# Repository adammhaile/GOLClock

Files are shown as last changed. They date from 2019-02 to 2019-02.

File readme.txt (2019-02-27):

Clock Faces and DIP switch settings:

000 - forwardClock - Shows the current time and date for 4 seconds, then plays "Conway's Game of Life" with the lit LEDs for the remainder of the minute.

001 - staticClock - Starts with completely random static, and then resolves to mostly clear numbers showing the date and time.  The "correctly" lit pixels still have a chance to turn off and vice versa, so it is never perfectly displayed. Requires some motion sensing ability to read the time.

010 - meltClock - Displays the current time and date, and then randomly makes lit pixels start falling to the bottom of the display. After about 15-20 seconds, becomes unreadable.

011 - brightClock - Each fully lit column is one hour in the day, starting from the left edge. Partially lit lines represent the portion of the current hour, with 3.75 minute resolution.

100 - backwardClock - Plays the Game of Life... but in reverse!  It iterates through the game about 30 steps, displays the output, then goes back to the start and iterates 29 times, shows the output, etc... until it's back to 0 steps, and then it just shows the correct time for a few seconds, until it starts the process over.  As the minute progresses, the display speeds up since it takes a non-trivial amount of time to iterate 30 times through the Game (roughly 3.1 seconds for 30 iterations, and .1 seconds for a single iteration.) 

101 - chartClock - Displays a bar graph that shows the approximate fraction of 5 different time durations, from top to bottom year, month, day, hour, and minute.  The minute hand has a 2.5 second resolution... Everything above that is way worse.

110 - binaryClock - Displays the current hours, minutes, and seconds, in binary format. Each row of boxes is one segment of the clock, and the filled boxes represent "on" bits of the time.

111 - epochClock - Displays the decimal notation of the current epoch time. *NOTE* it does not account for timezone differences. Not for use for mission critical timekeeping, because unless you live in GMT-0, it will be off.
ToDo: add in some sort of time zone functionality while setting the time. Of course, that would only be useful for this clock, so very low priority. 

Setting the clock: Hold both buttons until "Year 13" appears. Use the left hand button (when looking at the display) to advance the number, and the right hand button to change the set mode.  Hold down the right button to cancel out, and both buttons to save the new time and return to the clock function.  Note: In some clock faces, you may hold both buttons for more than a second, but the display won't change to the set mode until the start of the next minute.

Setting brightness: DIP switch #4 controls the brightness. Off is dim, on is bright.  The clock checks this setting at the top of each minute for most clocks, so it could take up to a minute for a change to take effect. (cycling power to the clock will force an update, of course)

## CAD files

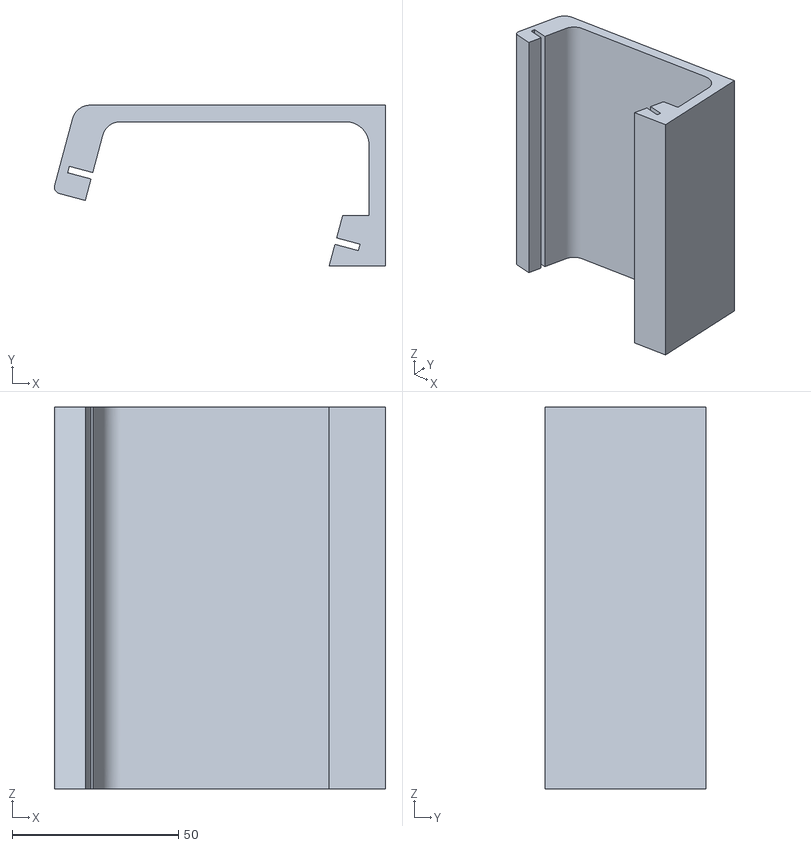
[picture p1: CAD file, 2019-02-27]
3D Models/STANDTHING_3D.stl
99.7 x 48.4 x 115.0

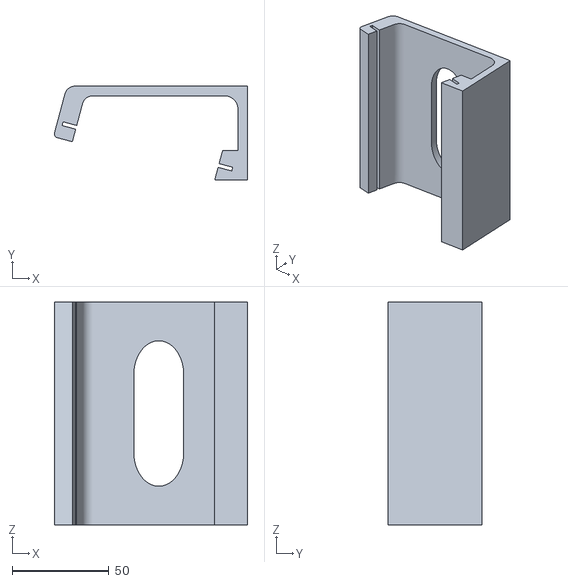
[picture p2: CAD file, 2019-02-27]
3D Models/STANDTHING_3D_Holy.stl
99.7 x 48.4 x 115.0

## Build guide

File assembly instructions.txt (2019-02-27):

Step 1: Solder together the pads on J5 on the back of the LED matrix. That tells the matrix that it's the first one in the chain.

Step 2: Solder the 10K resistor (Brown, Black, Orange) into R1

Step 3: Solder the 110 ohm resistor (Brown, Brown, Brown) into R2.

Step 4-whatever: Solder the rest of the components on the front of the board. Be sure the DIP switch panel is facing the right way up (the same orientation as the words "Josh Ward Game of Life Clock v1.0")

Step 5: Solder the 10-pin socket to P1, on the bottom of the board.

Step 6: Solder the 5-pin socket to the OUTSIDE pins of P2.  It will require a tiny bit of bending in order to place it in the socket.

Step 7: Plug the entire board into the back of the LED Matrix, ensuring that P1 is in the socket closest to J5.

Step 8: Plug it into a USB cable, and marvel at it actually working!  DIP settings below... Unplug and replug it to make sure new clock faces take effect immediately, and are cleanly drawn.

000 - forwardClock

001 - staticClock

010 - meltClock

011 - brightClock 

100 - backwardClock

101 - chartClock 

110 - binaryClock 

111 - epochClock 

Switch #4 is used for brightness settings.  Either very bright, or very dim.

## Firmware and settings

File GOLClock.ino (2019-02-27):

/*
* Conway's "Life" Clock works backwards, showing "random" display that reassembles to clock face... still in progress!
* It also does other modes, some of which are still being figured out and refined.
* Adapted from the Life example
* on the Processing.org site
*
* Further adapted by Josh Ward
* 
*/
#include <Wire.h>
#include "HT1632.h"
#include "RTClib.h"

RTC_DS1307 RTC;

#define DATA 12
#define WR   13
#define CS   4
#define DELAY 500

HT1632LEDMatrix matrix = HT1632LEDMatrix(DATA, WR, CS);

#include "globals.h"
#include "drawing.h"
#include "numbers.h"
#include "settime.h"
uint8_t BRIGHT = 1;

void setup() {
	timeRef = 0;

	//Set PORTD2 and PORTD3 as inputs
	DDRD &= ~(_BV(PIND2) | _BV(PIND3));
	//Enable set/change button pullups
	PORTD |= (_BV(PIND2) | _BV(PIND3));
	//Enable I2C pullups - probably not really necessary since twi.h does this for you
	PORTC |= (_BV(PINC4) | _BV(PINC5));

	//see setResetDisable(bool) for info
	DDRD &= ~(_BV(PIND5)); //Set PIND5 as input initially
	PORTD |= (_BV(PIND5)); //Set high

	//check for buttons held down at power up
	bSave = BUTTON_STATE;

	Serial.begin(115200);
	Wire.begin();
	RTC.begin();

	pinMode(17, OUTPUT); //These two are ONLY used while it's on the Arduino. When moved to actual device, delete these!
	pinMode(16, OUTPUT);

	pinMode(8, INPUT);
	pinMode(9, INPUT);
	pinMode(10, INPUT);
	pinMode(11, INPUT);
	digitalWrite(2, HIGH);
	digitalWrite(3, HIGH);
	digitalWrite(8, HIGH);
	digitalWrite(9, HIGH);
	digitalWrite(10, HIGH);
	digitalWrite(11, HIGH);

	digitalWrite(17, HIGH); //These two are ONLY used while it's on the Arduino. When moved to actual device, delete these!
	digitalWrite(16, LOW);

	if (digitalRead(11) == LOW)
		BRIGHT = 1;
	else if (digitalRead(11) == HIGH)
		BRIGHT = 5;

	matrix.begin(HT1632_COMMON_16NMOS); 
	matrix.setBrightness(BRIGHT);
	matrix.fillScreen();
	delay(500);
	matrix.clearScreen();

	uint8_t hour = 0;
	uint8_t hourten = 0;
	uint8_t hourone = 0;
	uint8_t minute = 0;
	uint8_t minuteten = 0;
	uint8_t minuteone = 0;
	uint8_t top = 0;
	uint8_t egg = 0;

	//Grab current time and set to compile time if RTC is uniitialized

	dt_now = RTC.now();

	if(dt_now.unixtime() <= 946684860) //RTC not initialized and oscillator disabled
	{
		dt_now = DateTime(__DATE__, __TIME__);
		RTC.adjust(dt_now);
	}

	setInterrupts();
	setupDisplayTimer();
}

void loop() {
	if(curState == STATE_CLOCK)
	{  
		static DateTime now;
		now = RTC.now();
		dt_now = RTC.now();
		if (digitalRead(11) == HIGH)
			BRIGHT = 1;
		else if (digitalRead(11) == LOW)
			BRIGHT = 15;
		matrix.setBrightness(BRIGHT);
		if ((digitalRead(8) == HIGH) && (digitalRead(9) == HIGH) && (digitalRead(10) == HIGH)) //000
			forwardClock(now);
		else if ((digitalRead(8) == HIGH) && (digitalRead(9) == HIGH) && (digitalRead(10) == LOW)) //001
			staticClock(now);
		else if ((digitalRead(8) == HIGH) && (digitalRead(9) == LOW) && (digitalRead(10) == HIGH)) //010
			meltClock(now);
		else if ((digitalRead(8) == HIGH) && (digitalRead(9) == LOW) && (digitalRead(10) == LOW)) //011
			brightClock(now);
		else if ((digitalRead(8) == LOW) && (digitalRead(9) == HIGH) && (digitalRead(10) == HIGH)) //100
			backwardClock(now);
		else if ((digitalRead(8) == LOW) && (digitalRead(9) == HIGH) && (digitalRead(10) == LOW)) //101
			chartClock(now);
		else if ((digitalRead(8) == LOW) && (digitalRead(9) == LOW) && (digitalRead(10) == HIGH)) //110
			binaryClock(now);
		else if ((digitalRead(8) == LOW) && (digitalRead(9) == LOW) && (digitalRead(10) == LOW)) //111
			epochClock(now);
	}
	else if(curState == STATE_MANUAL_SET)
	{
		matrix.setTextSize(1);    // size 1 == 8 pixels high
		matrix.setTextColor(1);   // 'lit' LEDs
		if(timeReady)
		{
			adjustFromSetVal();
			curState = STATE_CLOCK; 
		}
		else if(setChanged)
		{

			//This is where all the time setting code goes!
			switch(curSet) {
			case SET_YR:
				matrix.clearScreen(); 
				matrix.setCursor(0, 0);   // start at top left, with one pixel of spacing
				matrix.print("Year ");
				matrix.setCursor(0, 8);   // next line, 8 pixels down
				matrix.print(setValues[SET_YR]);
				matrix.writeScreen();
				break;
			case SET_MON:
				matrix.clearScreen(); 
				matrix.setCursor(0, 0);   // start at top left, with one pixel of spacing
				matrix.print("Mon ");
				matrix.setCursor(0, 8);   // next line, 8 pixels down
				matrix.print(setValues[SET_MON]);
				matrix.writeScreen();
				break;
			case SET_DAY:
				matrix.clearScreen(); 
				matrix.setCursor(0, 0);   // start at top left, with one pixel of spacing
				matrix.print("Day ");
				matrix.setCursor(0, 8);   // next line, 8 pixels down
				matrix.print(setValues[SET_DAY]);
				matrix.writeScreen();
				break;
			case SET_HR:
				matrix.clearScreen(); 
				matrix.setCursor(0, 0);   // start at top left, with one pixel of spacing
				matrix.print("Hour ");
				matrix.setCursor(0, 8);   // next line, 8 pixels down
				matrix.print(setValues[SET_HR]);
				matrix.writeScreen();  
				break;
			case SET_MIN:
				matrix.clearScreen(); 
				matrix.setCursor(0, 0);   // start at top left, with one pixel of spacing
				matrix.print("Min ");
				matrix.setCursor(0, 8);   // next line, 8 pixels down
				matrix.print(setValues[SET_MIN]);
				matrix.writeScreen(); 
				break; 
			}
			setChanged = false;
		}
		else if(setCancel)
		{
			curState = STATE_CLOCK;
		}

	}
}

void backwardClock(DateTime now) {
	DateTime future = now.unixtime() + 60; //it's gonna be the future soon
	displayTime(future);
	for (int bigsteps = 29; bigsteps > -1; bigsteps--) {
		// 32 steps is the most I can fit in a minute right now.  
		//save the time back into world 0
		for (uint8_t y = 0; y < matrix.height(); y++) { 
			for (uint8_t x = 0; x < matrix.width(); x++) {
				setDispPixel(x, y, 0, getDispPixel(x, y, 2));
			}
		}
		cycle(bigsteps); // Play the game of life "bigsteps" number of times 
	} //end for loop

} //end backwardClock



void forwardClock(DateTime now) {
	displayTime(now);
	for (uint8_t y = 0; y < matrix.height(); y++) { 
		for (uint8_t x = 0; x < matrix.width(); x++) {
			setDispPixel(x, y, 0, getDispPixel(x, y, 2));
		}
	}

	displayFrame();
	delay(4000);
	for (uint8_t y = 0; y < matrix.height(); y++) { 
		for (uint8_t x = 0; x < matrix.width(); x++) {
			setDispPixel(x, y, 0, getDispPixel(x, y, 2));
		}
	}
	while(1) { 
		//save the time back into world 0

		for (uint8_t y = 0; y < matrix.height(); y++) { 
			for (uint8_t x = 0; x < matrix.width(); x++) {
				// Default is for cell to stay the same
				setDispPixel(x, y, 1, getDispPixel(x, y, 0));
				uint8_t count = neighbours(x, y); 

				if (count == 3 && !(getDispPixel(x, y, 0))) {
					// A new cell is born
					setDispPixel(x, y, 1, 1);
				} 

				if ((count < 2 || count > 3) && getDispPixel(x, y, 0)) {
					// Cell dies
					setDispPixel(x, y, 1, 0);
				}
			}
		}
		// Copy next generation into place
		for (uint8_t y = 0; y < matrix.height(); y++) { 
			for (uint8_t x = 0; x < matrix.width(); x++) {
				setDispPixel(x, y, 0, getDispPixel(x, y, 1));
			} 
		}
		displayFrame();
		DateTime now = RTC.now();
		if (now.second() >= 58)
			break;

	} //end GOL loop
} //end forwardClock

void staticClock(DateTime now) { //Cull the current time out of static...
	displayTime(now);

	randomSeed(analogRead(5));
	for (uint8_t y = 0; y < matrix.height(); y++) { 
		for (uint8_t x = 0; x < matrix.width(); x++) {
			randPixel(x, y, 0, 90);
		}
	}
	displayFrame();
	while (1) {  
		for (uint8_t y = 0; y < matrix.height(); y++) { 
			for (uint8_t x = 0; x < matrix.width(); x++) {
				if ((getDispPixel(x, y, 0) == getDispPixel(x, y, 2)) && !(getDispPixel(x, y, 0))) {
					if (random(100) < 80) //Change 80 for different densities of correct pixels
						setDispPixel(x, y, 1, getDispPixel(x, y, 0));
					else
						randPixel(x, y, 1, 50);
				} 
				else if ((getDispPixel(x, y, 0) == getDispPixel(x, y, 2)) && (getDispPixel(x, y, 0))) {
					if (random(100) < 98) //Change 98 for different densities of correct pixels
						setDispPixel(x, y, 1, getDispPixel(x, y, 0));
					else
						randPixel(x, y, 1, 50);
				}
				else {
					randPixel(x, y, 1, 50);
				}
			}
		}
		//copy new frame into current  
		for (uint8_t y = 0; y < matrix.height(); y++) { 
			for (uint8_t x = 0; x < matrix.width(); x++) {
				setDispPixel(x, y, 0, getDispPixel(x, y, 1));
			} 
		}
		displayFrame();
		DateTime now = RTC.now();
		if (now.second() >= 58)
			break;
	}
} // end staticClock


void meltClock(DateTime now) { //melt the time...
	displayTime(now);
	for (uint8_t y = 0; y < matrix.height(); y++) { //show the current time
		for (uint8_t x = 0; x < matrix.width(); x++) {
			setDispPixel(x, y, 0, getDispPixel(x, y, 2));
		} 
	}
	displayFrame();
	delay(4000);
	randomSeed(analogRead(5));

	while (1) {  
		for (uint8_t y = 0; y < matrix.height(); y++) { 
			for (uint8_t x = 0; x < matrix.width(); x++) {
				meltPixel(x, y, 1, 2);
			}
		}
		//copy new frame into current  
		for (uint8_t y = 0; y < matrix.height(); y++) { 
			for (uint8_t x = 0; x < matrix.width(); x++) {
				setDispPixel(x, y, 0, getDispPixel(x, y, 1));
			} 
		}
		displayFrame();
		DateTime now = RTC.now();
		if (now.second() >= 58)
			break;
	}
} // end meltClock

void brightClock(DateTime now) {
	uint8_t hrs = now.hour();
	uint8_t partial = ((now.minute() * 60) + now.second())/225;
	for (uint8_t y = 0; y < matrix.height(); y++) { 
		for (uint8_t x = 0; x < matrix.width(); x++) {
			if (x < hrs) { //complete rows
				setDispPixel(x, y, 0, 1);
			}
			else if (x == hrs) { //part of row... seconds / 225 for a height of 16.
				if (y < partial) {
					setDispPixel(x, y, 0, 1);
				}
				else {
					setDispPixel(x, y, 0, 0);
				}
			}
			else { // row off
				setDispPixel(x, y, 0, 0);
			}
		} 
	}

	displayFrame();
}

void chartClock(DateTime now) {
	//Get julian date
	int partyear, partmonth, partday, parthour, partminute = 0;
	uint8_t m = now.month();
	uint8_t d = now.day();
	uint8_t h = now.hour();
	uint8_t mm = now.minute();
	uint8_t s = now.second();
	int jd = now.day();
	if (m > 1)  jd += 31;
	if (m > 2)  jd += 28; // doesn't count leapyears... good enough.
	if (m > 3)  jd += 31;
	if (m > 4)  jd += 30;
	if (m > 5)  jd += 31;
	if (m > 6)  jd += 30;
	if (m > 7)  jd += 31;
	if (m > 8)  jd += 31;
	if (m > 9)  jd += 30;
	if (m > 10) jd += 31;
	if (m > 11) jd += 30;

	partyear = jd / 15.2;

	partmonth = (d * 24 + h) / (pgm_read_byte(&daysInMonth[m - 1]));

	partday = (h * 60 + mm)/60;

	parthour = ((now.minute() * 60) + now.second())/150;

	partminute = s / 2.5;

	for (uint8_t y = 0; y < 16; y++) {
		for (uint8_t x = 0; x < 24; x++) {
			if ((y == 1) || (y == 2)) {
				if (partyear > x) {
					setDispPixel(x, y, 0, 1);
				}
				else setDispPixel(x, y, 0, 0);
			}
			if ((y == 4) || (y == 5)) {
				if (partmonth > x) {
					setDispPixel(x, y, 0, 1);
				}
				else setDispPixel(x, y, 0, 0);
			}
			if ((y == 7) || (y == 8)) {
				if (partday > x) {
					setDispPixel(x, y, 0, 1);
				}
				else setDispPixel(x, y, 0, 0);
			}
			if ((y == 10) || (y == 11)) {
				if (parthour > x) {
					setDispPixel(x, y, 0, 1);
				}
				else setDispPixel(x, y, 0, 0);
			}
			if ((y == 13) || (y == 14)) {
				if (partminute > x) {
					setDispPixel(x, y, 0, 1);
				}
				else setDispPixel(x, y, 0, 0);
			}
		}
	}
	displayFrame();
} //end chartClock

void binaryClock(DateTime now){

	uint8_t month = now.month();
	uint8_t day = now.day();
	uint8_t	hour = now.hour();
	uint8_t minute = now.minute();
	uint8_t second = now.second();

	//setup grid
	drawRect(4, 0, 3, 3, 1);
	drawRect(8, 0, 3, 3, 1);
	drawRect(12, 0, 3, 3, 1);
	drawRect(16, 0, 3, 3, 1);
	drawRect(20, 0, 3, 3, 1);

	drawRect(0, 6, 3, 3, 1);
	drawRect(4, 6, 3, 3, 1);
	drawRect(8, 6, 3, 3, 1);
	drawRect(12, 6, 3, 3, 1);
	drawRect(16, 6, 3, 3, 1);
	drawRect(20, 6, 3, 3, 1);

	drawRect(0, 12, 3, 3, 1);
	drawRect(4, 12, 3, 3, 1);
	drawRect(8, 12, 3, 3, 1);
	drawRect(12, 12, 3, 3, 1);
	
	drawRect(16, 12, 3, 3, 1);
	drawRect(20, 12, 3, 3, 1);

	//HOUR
	if (hour >= 16){
		drawPixel(5, 1, 1);
		hour -= 16;
	}
	else drawPixel(5, 1, 0);
	if (hour >= 8){
		drawPixel(9, 1, 1);
		hour -= 8;
	}
	else drawPixel(9, 1, 0);

	if (hour >= 4){
		drawPixel(13, 1, 1);
		hour -= 4;
	}
	else drawPixel(13, 1, 0);

	if (hour >= 2) {
		drawPixel(17, 1, 1);
		hour -= 2;
	}
	else drawPixel(17, 1, 0);

	if (hour >= 1) {
		drawPixel(21, 1, 1);
	}
	else drawPixel(21, 1, 0);

	//MINUTE
	if (minute >= 32){
		drawPixel(1, 7, 1);
		minute -= 32;
	}
	else drawPixel(1, 7, 0);
	if (minute >= 16){
		drawPixel(5, 7, 1);
		minute -= 16;
	}
	else drawPixel(5, 7, 0);
	if (minute >= 8){
		drawPixel(9, 7, 1);
		minute -= 8;
	}
	else drawPixel(9, 7, 0);

	if (minute >= 4){
		drawPixel(13, 7, 1);
		minute -= 4;
	}
	else drawPixel(13, 7, 0);

	if (minute >= 2) {
		drawPixel(17, 7, 1);
		minute -= 2;
	}
	else drawPixel(17, 7, 0);

	if (minute >= 1) {
		drawPixel(21, 7, 1);
	}
	else drawPixel(21, 7, 0);

	//SECOND
	if (second >= 32){
		drawPixel(1, 13, 1);
		second -= 32;
	}
	else drawPixel(1, 13, 0);
	if (second >= 16){
		drawPixel(5, 13, 1);
		second -= 16;
	}
	else drawPixel(5, 13, 0);
	if (second >= 8){
		drawPixel(9, 13, 1);
		second -= 8;
	}
	else drawPixel(9, 13, 0);

	if (second >= 4){
		drawPixel(13, 13, 1);
		second -= 4;
	}
	else drawPixel(13, 13, 0);

	if (second >= 2) {
		drawPixel(17, 13, 1);
		second -= 2;
	}
	else drawPixel(17, 13, 0);

	if (second >= 1) {
		drawPixel(21, 13, 1);
	}
	else drawPixel(21, 13, 0);

	displayFrame();
	delay(100);

} //end binaryClock

void epochClock(DateTime now) {
	static uint32_t unix;
	unix = now.unixtime();

	matrix.fillRect(0,0,24,16,0);
	setCursor(0, 0);
	setTextColor(1);

	static char topS[6]; //6 bytes for null terminator!
	getUnixStringSeg(unix / 100000, topS);
	static char botS[6]; //static so we don't keep allocating this
	getUnixStringSeg(unix % 100000, botS);

	printSm(topS);
	setCursor(0, 8);
	printSm(botS);
	matrix.writeScreen();

	delay(100);

} //end epochClock

uint8_t meltPixel (uint8_t x, uint8_t y, uint8_t z, uint8_t seed) {
	if (getDispPixel(x, y - 1, 0) && (random(100) < seed)) {
		if (randPixel(x, y, 1, 50) == 1)
			setDispPixel(x, y - 1, 1, 0);
		else
			setDispPixel(x, y, 1, getDispPixel(x, y, 0));
	}
	else
		setDispPixel(x, y, 1, getDispPixel(x, y, 0));
}

bool randPixel (uint8_t x, uint8_t y, uint8_t z, uint8_t seed) {
	if (random(100) < seed)
		setDispPixel(x, y, z, 1);
	else
		setDispPixel(x, y, z, 0);
	return getDispPixel(x, y, z);
}

void cycle(byte bigsteps) {  //this plays the game in reverse
	byte backsteps = bigsteps;
	while (backsteps >= 1) {

		for (uint8_t y = 0; y < matrix.height(); y++) { 
			for (uint8_t x = 0; x < matrix.width(); x++) {
				// Default is for cell to stay the same
				setDispPixel(x, y, 1, getDispPixel(x, y, 0));
				uint8_t count = neighbours(x, y); 

				if (count == 3 && !(getDispPixel(x, y, 0))) {
					// A new cell is born
					setDispPixel(x, y, 1, 1);
				} 

				if ((count < 2 || count > 3) && (getDispPixel(x, y, 0))) {
					// Cell dies
					setDispPixel(x, y, 1, 0);
				}
			}
		}
		backsteps--;
		// Copy next generation into place
		for (uint8_t y = 0; y < matrix.height(); y++) { 
			for (uint8_t x = 0; x < matrix.width(); x++) {
				setDispPixel(x, y, 0, getDispPixel(x, y, 1));
			} 
		}
	}
	displayFrame();
} //end cycle

void displayFrame() { //Spit current frame out to the display
	_displayUpdated = true;
	delay(DELAY);
} //end displayFrame

void clearFrame() { //clears all buffers and starts fresh
	for (uint8_t y = 0; y<matrix.height(); y++) {
		for (uint8_t x = 0; x< matrix.width(); x++) {
			for (uint8_t z = 0; z < 3; z++) {
				setDispPixel(x, y, z, 0);
			}
		}
	}


}

int neighbours(int x, int y) { //Calculate how many living neighbors each pixel has.
	return  getDispPixel((x + 1) % matrix.width(), y, 0) +
		getDispPixel(x, ((y + 1) % matrix.height()), 0) +
		getDispPixel((x + matrix.width() - 1) % matrix.width(), y, 0) +
		getDispPixel(x, (y + matrix.height() - 1) % matrix.height(), 0) +
		getDispPixel((x + 1) % matrix.width(), (y + 1) % matrix.height(), 0) +
		getDispPixel((x + matrix.width() - 1) % matrix.width(), (y + 1) % matrix.height(), 0) +
		getDispPixel((x + matrix.width() - 1) % matrix.width(), (y + matrix.height() - 1) % matrix.height(), 0) +
		getDispPixel((x + 1) % matrix.width(), (y + matrix.height() - 1) % matrix.height(), 0);
} //end neighbors


void displayTime(DateTime now) {
	//clear the disply and clock buffer
	for (uint8_t y = 0; y < matrix.height(); y++) { 
		for (uint8_t x = 0; x < matrix.width(); x++) {
			setDispPixel(x, y, 0, 0);
			setDispPixel(x, y, 2, 0);
		}
	}

	uint8_t top = 0;
	uint8_t hour = now.hour();
	uint8_t minute = now.minute();

	uint8_t bottom = 8;
	uint8_t day = now.day();
	uint8_t month = now.month();

	char hours[3];
	memset(hours, 0, sizeof(char)* 3);
	itoa(hour, hours, DEC);
	char minutes[3];
	memset(minutes, 0, sizeof(char)* 3);
	itoa(minute, minutes, DEC);
	char months[3];
	memset(months, 0, sizeof(char)* 3);
	itoa(month, months, DEC);
	char days[3];
	memset(days, 0, sizeof(char)* 3);
	itoa(day, days, DEC);

	setCursor(0, 0);
	setTextColor(1);

	if (hour < 10)
		printSm(" ");
	printSm(hours);
	printSm(":");
	if (minute < 10)
		printSm("0");
	printSm(minutes);
	setCursor(0, 8);
	if (month < 10)
		printSm(" ");
	printSm(months);
	printSm("/");
	if (day < 10)
		printSm("0");
	printSm(days);

	//save it into world 2
	for (uint8_t y = 0; y < matrix.height(); y++) { 
		for (uint8_t x = 0; x < matrix.width(); x++) {
			setDispPixel(x, y, 2, getDispPixel(x, y, 0));
			setDispPixel(x, y, 0, 0);//clear out world 0 again
		}
	}

} //end displaytime

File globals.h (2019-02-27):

#ifndef __GLOBALS__
#define __GLOBALS__

#include "Arduino.h"
#include "RTCLib.h"

#define MATRIX_HEIGHT 16
#define MATRIX_WIDTH  24

unsigned long timeRef;
unsigned long timeOutRef;
//uint8_t pwmStep = 0;
//const uint8_t pwmMax = 16;
//volatile uint8_t pwmLevel = 10; //range 5 - 10 (50% - 100%)
bool fadeDir = false;

//RTC Keeping method
#define USE_DS1307   0

//Change this to one of the three above to change which chip (or software) is used
#define RTC_METHOD USE_DS1307

//RTC_Base *RTC = NULL;

volatile uint8_t bSave = 0;
volatile uint16_t bCount = 0;
volatile boolean holdFlag = false;
uint16_t holdMax = 60;

//Valid state machine states
#define STATE_CLOCK      0
#define STATE_MANUAL_SET 1
volatile uint8_t curState = STATE_CLOCK;

//For manually setting the time and used with curSet
#define SET_YR   	0
#define SET_MON 	1
#define SET_DAY		2
#define SET_HR		3
#define SET_MIN	        4

//helpers for button handling
#define BUTTON_A _BV(PIND2)
#define BUTTON_B _BV(PIND3)
#define BUTTON_MASK (BUTTON_A | BUTTON_B)
#define BUTTON_STATE PIND & BUTTON_MASK

//Who can ever remember what the prescaler combinations are?
//These are for Timer0
#define PRESCALE0_1 _BV(CS00)
#define PRESCALE0_8 _BV(CS01)
#define PRESCALE0_64 (_BV(CS01) | _BV(CS00))
#define PRESCALE0_256 _BV(CS02)
#define PRESCALE0_1024 (_BV(CS02) | _BV(CS00))

//These are for Timer1
#define PRESCALE1_1 _BV(CS10)
#define PRESCALE1_8 _BV(CS11)
#define PRESCALE1_64 (_BV(CS11) | _BV(CS10))
#define PRESCALE1_256 _BV(CS12)
#define PRESCALE1_1024 (_BV(CS12) | _BV(CS10))

//These are for Timer2
#define PRESCALE2_1 _BV(CS20)
#define PRESCALE2_8 _BV(CS21)
#define PRESCALE2_32 (_BV(CS21) | _BV(CS20))
#define PRESCALE2_64 _BV(CS22)
#define PRESCALE2_128 (_BV(CS20) | _BV(CS22))
#define PRESCALE2_256 (_BV(CS22) | _BV(CS21))
#define PRESCALE2_1024 (_BV(CS22) | _BV(CS21) | _BV(CS20))

volatile uint8_t curSet = SET_YR;
volatile uint8_t setValues[5] = {
	0,0,0,0,0};
DateTime dt_now = DateTime();
bool setChanged = false;
bool timeUpdated = false;
bool timeReady = false;
bool setCancel = false;

//Limits for each field value and for months
//Store in progmem since they are rarely used.
PROGMEM const uint8_t
	//YY . MM . DD   HH : MM
	limit[]       = {  
		36,  12,  31,  23,  59} //limiting year to 36, since 99 is just asking for problems.
,
	daysInMonth[] = { 
		31, 28, 31, 30, 31, 30, 31, 31, 30, 31, 30, 31 };

//helpers for handling world pixels
uint8_t world[3][24][2];
uint8_t worldIndex[3] = {0,1,2};

volatile bool _displayUpdated = false;

void clearWorld(uint8_t num = 0)
{
	noInterrupts();
	if(num < 0 || num > 2) return;
	num = worldIndex[num];
	memset(world[num], 0, 48);
	interrupts();
}
__attribute__((noinline)) bool getDispPixel(uint8_t x, uint8_t y, uint8_t num)
{
	static uint8_t rowByte = 0; // 0 means top 8, 1 means bottom 8
	static uint8_t rowBit = 0;

	if(num < 0 || num > 2) return false;
	num = worldIndex[num];

	rowByte = y >> 3;
	rowBit = y&7;

	return (world[num][x][rowByte] & (1 << rowBit)) > 0;
}

__attribute__((noinline)) void setDispPixel(uint8_t x, uint8_t y, uint8_t num, bool state)
{
	static uint8_t rowByte = 0; // 0 means top 8, 1 means bottom 8
	static uint8_t rowBit = 0;

	if(num < 0 || num > 2) return;
	num = worldIndex[num];
	
	rowByte = y >> 3;
	rowBit = y&7;

	if(state)
		world[num][x][rowByte] |= (1 << rowBit);
	else
		world[num][x][rowByte] &= ~(1 << rowBit);
}
static const unsigned char  fontSm[] PROGMEM = {
	0x00, 0x00, 0x00, 0x00,
	0x00, 0x00, 0x00, 0x00,
	0x00, 0x00, 0x00, 0x00,
	0x00, 0x00, 0x00, 0x00,
	0x00, 0x00, 0x00, 0x00,
	0x00, 0x00, 0x00, 0x00,
	0x00, 0x00, 0x00, 0x00,
	0x00, 0x00, 0x00, 0x00,
	0x00, 0x00, 0x00, 0x00,
	0x00, 0x00, 0x00, 0x00,
	0x00, 0x00, 0x00, 0x00,
	0x00, 0x00, 0x00, 0x00,
	0x00, 0x00, 0x00, 0x00,
	0x00, 0x00, 0x00, 0x00,
	0x00, 0x00, 0x00, 0x00,
	0x00, 0x00, 0x00, 0x00,
	0x00, 0x00, 0x00, 0x00,
	0x00, 0x00, 0x00, 0x00,
	0x00, 0x00, 0x00, 0x00,
	0x00, 0x00, 0x00, 0x00,
	0x00, 0x00, 0x00, 0x00,
	0x00, 0x00, 0x00, 0x00,
	0x00, 0x00, 0x00, 0x00,
	0x00, 0x00, 0x00, 0x00,
	0x00, 0x00, 0x00, 0x00,
	0x00, 0x00, 0x00, 0x00,
	0x00, 0x00, 0x00, 0x00,
	0x00, 0x00, 0x00, 0x00,
	0x00, 0x00, 0x00, 0x00,
	0x00, 0x00, 0x00, 0x00,
	0x00, 0x00, 0x00, 0x00,
	0x00, 0x00, 0x00, 0x00,
	0x00, 0x00, 0x00, 0x00,
	0x00, 0x00, 0x00, 0x00,
	0x00, 0x00, 0x00, 0x00,
	0x00, 0x00, 0x00, 0x00,
	0x00, 0x00, 0x00, 0x00,
	0x00, 0x00, 0x00, 0x00,
	0x00, 0x00, 0x00, 0x00,
	0x00, 0x00, 0x00, 0x00,
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
};

void getUnixStringSeg(uint16_t sub, char * output)
{
	memset(output, 0, 6);
	static uint8_t val = 0;
	for(int i = 4; i>=0; i--)
	{
		val = sub % 10;
		output[i] = 48+val;
		sub = sub / 10;
	}
	output[5] = 0;
}



#endif
